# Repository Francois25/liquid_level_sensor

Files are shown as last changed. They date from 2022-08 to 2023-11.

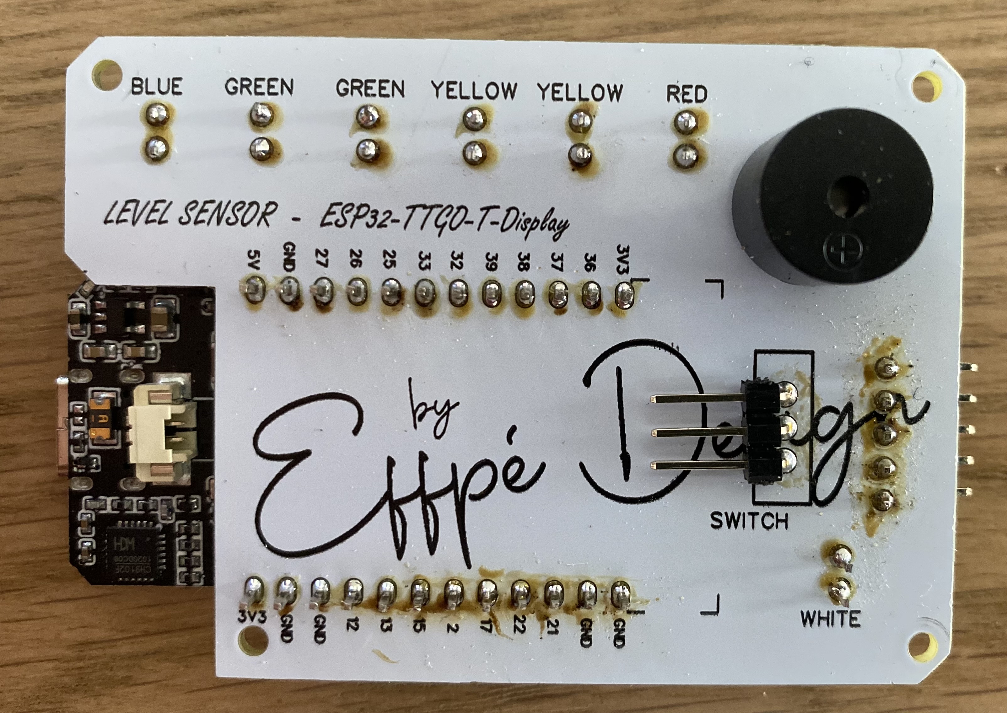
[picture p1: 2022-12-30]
Docs/pictures/IMG_4034.jpg

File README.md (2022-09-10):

# Liquid level sensor for tank presentation :

The tank liquid level sensor is an ultrasonic sensor housing. One housing is used to measure the height of a liquid in a rectangular tank and the other contains an analogue display of the data by means of coloured LEDs. The digital display is shown on the screen of an ESP32-TTGO-T-Display and on a web page.

# Micropython firmware :
The firmware used is Micropython, downloadable here: [MicroPython firmware for ESP32](https://micropython.org/download/esp32spiram/)  
The use of Picoweb allows to transmit the information on the web page using the address corresponding to the IP of the ESP card

# How it works : 
The ultrasonic sensor used here is the HCSR04. Coupled to this sensor is another temperature and humidity sensor, the DHT22 in order to calibrate the speed of sound in relation to temperature and humidity. In my case, the humidity had very little influence on the value of the ultrasonic measurement, so I didn't pay attention to it.
In the main.py file it is necessary to enter your own SSId and password on lines 15 and 16.

If there is a problem with the ultrasonic sensor, the screen will display an error message in red on a black background, so check the status of the sensor in the tank.
If there is a problem with the temperature sensor, the screen displays in red on a yellow background the temperature at 15° and the humidity at 0%.

All the libraries for the project to be functional can be found in the folder [/lib](https://github.com/Francois25/liquid_level_sensor/tree/master/lib)
All the fonts for the project to be functional are in the folder [/font](https://github.com/Francois25/liquid_level_sensor/tree/master/font)

# Addon :
The files needed to make the project work are in the folder [/Docs](https://github.com/Francois25/liquid_level_sensor/tree/master/Docs), you have BOM for buy all the parts you need, and a wiring diagram and Gerber ZIP.
You can find all 3D files for print different parts on folder [/STL](https://github.com/Francois25/liquid_level_sensor/tree/master/STL)

# Acknowledgements:
A big thank you to my friend Roel Jaspers who is always there when I get stuck on the code... Big Up Cyberjunkie.

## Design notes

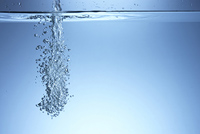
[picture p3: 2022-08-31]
web/goutte_eau.jpg

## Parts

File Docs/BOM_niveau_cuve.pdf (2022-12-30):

ID | Name | Designator | Footprint | Quantity
1 | HCSR04 | H1 | 20201128 SMA HCSR04 | 1
2 | LED-TH-5mm_Green | LED1,LED6 | LED-TH_BD5.0_GREEN | 2
3 | LED-TH-5mm_Red | LED2 | LED-TH_BD5.0_RED | 1
4 | LED-TH-5mm_White | LED3 | LED-TH_BD5.0_GREEN | 1
5 | LED-TH-5mm_Yellow | LED4,LED5 | LED-TH_BD5.0_RED | 2
6 | LED-TH-5mm_Blue | LED7 | LED-TH_BD5.0_BLUE | 1
7 | ESP32-TTGO-T-Display-V1.0 | P1 | ESP32-2X12-TTGO-TDISPLAY | 1
8 | 10k | R1,R2,R3,R4,R5,R6,R8 | R0805 | 7
9 | 390 | R7 | R0805 | 1
10 | SWITCH 2 positions | S2 | SWITCH-SPDT | 1
11 | Buzzer | U2 | BUZZER | 1
12 | DHT22 | U3 | SENSOR-TH_DHT11 | 1

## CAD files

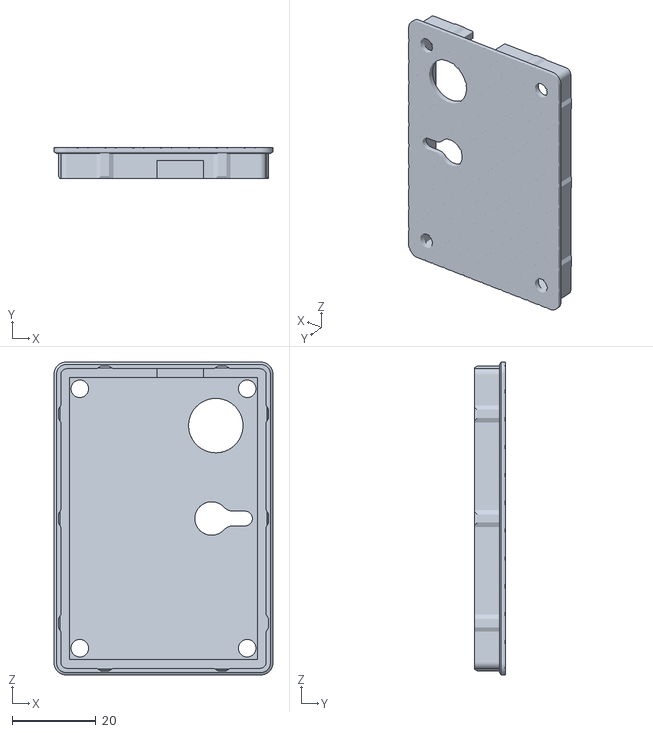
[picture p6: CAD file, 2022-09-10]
Docs/3D_print_STL/box_esp_rear.stl
52.3 x 7.50 x 74.8

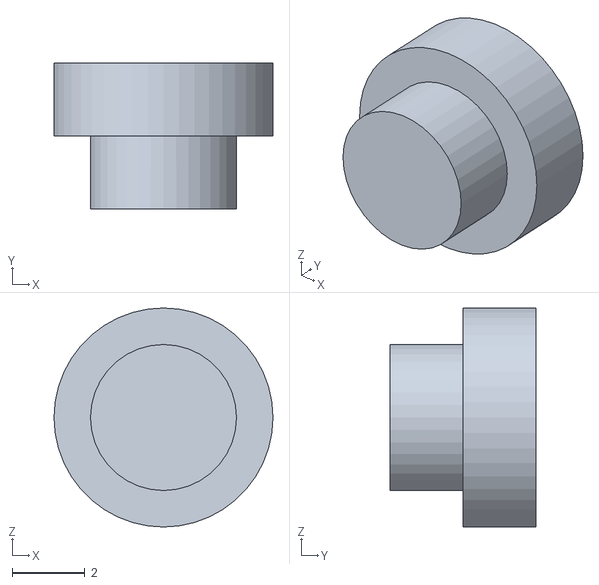
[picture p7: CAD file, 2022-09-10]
Docs/3D_print_STL/box_foot_rear.stl
6.00 x 4.00 x 6.00

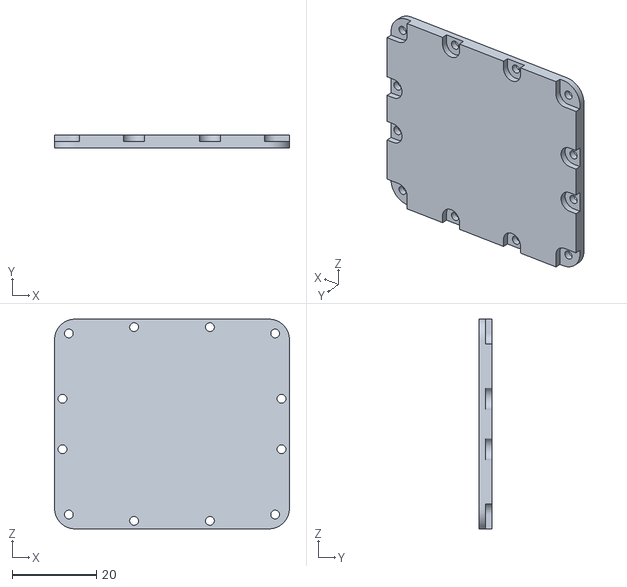
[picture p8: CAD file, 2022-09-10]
Docs/3D_print_STL/fond_boitier_hcsr04.stl
55.8 x 3.00 x 49.8

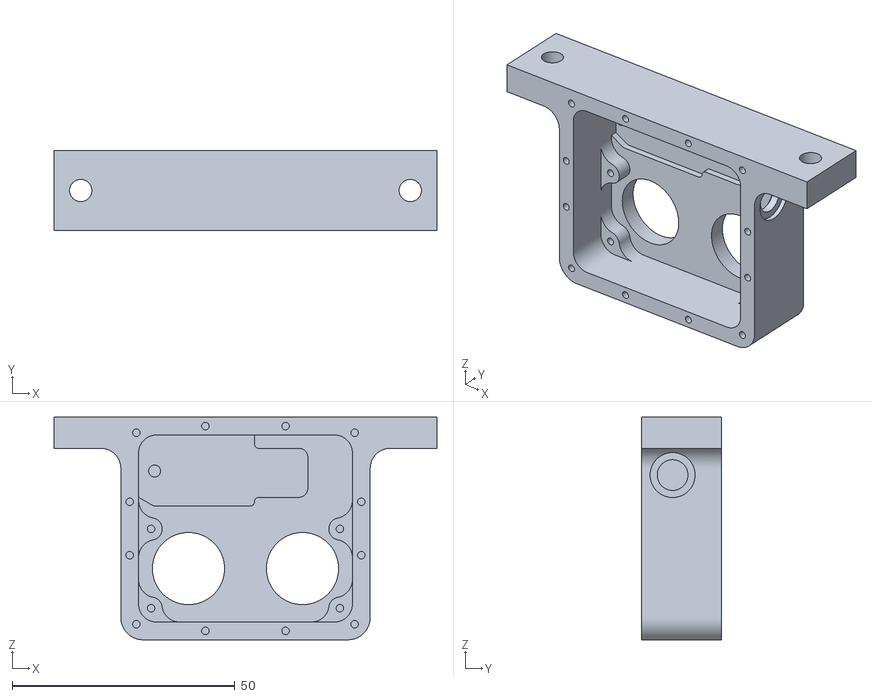
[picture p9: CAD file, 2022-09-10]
Docs/3D_print_STL/boitier_hcsr04.stl
86.0 x 18.0 x 50.0

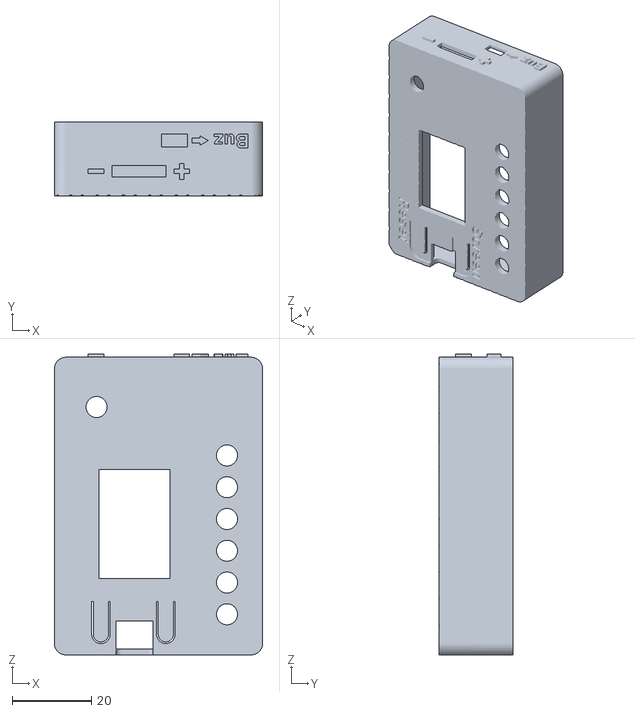
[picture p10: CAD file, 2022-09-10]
Docs/3D_print_STL/box_esp_sup.stl
52.5 x 18.6 x 75.8

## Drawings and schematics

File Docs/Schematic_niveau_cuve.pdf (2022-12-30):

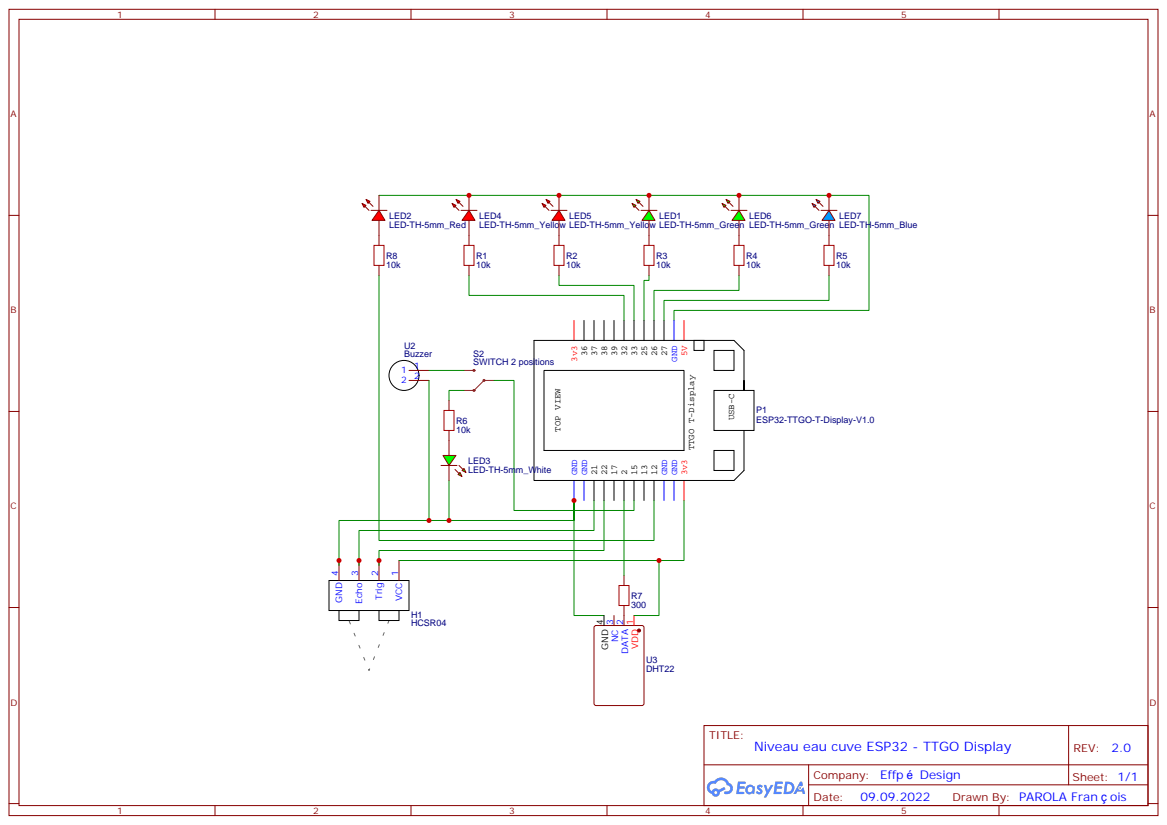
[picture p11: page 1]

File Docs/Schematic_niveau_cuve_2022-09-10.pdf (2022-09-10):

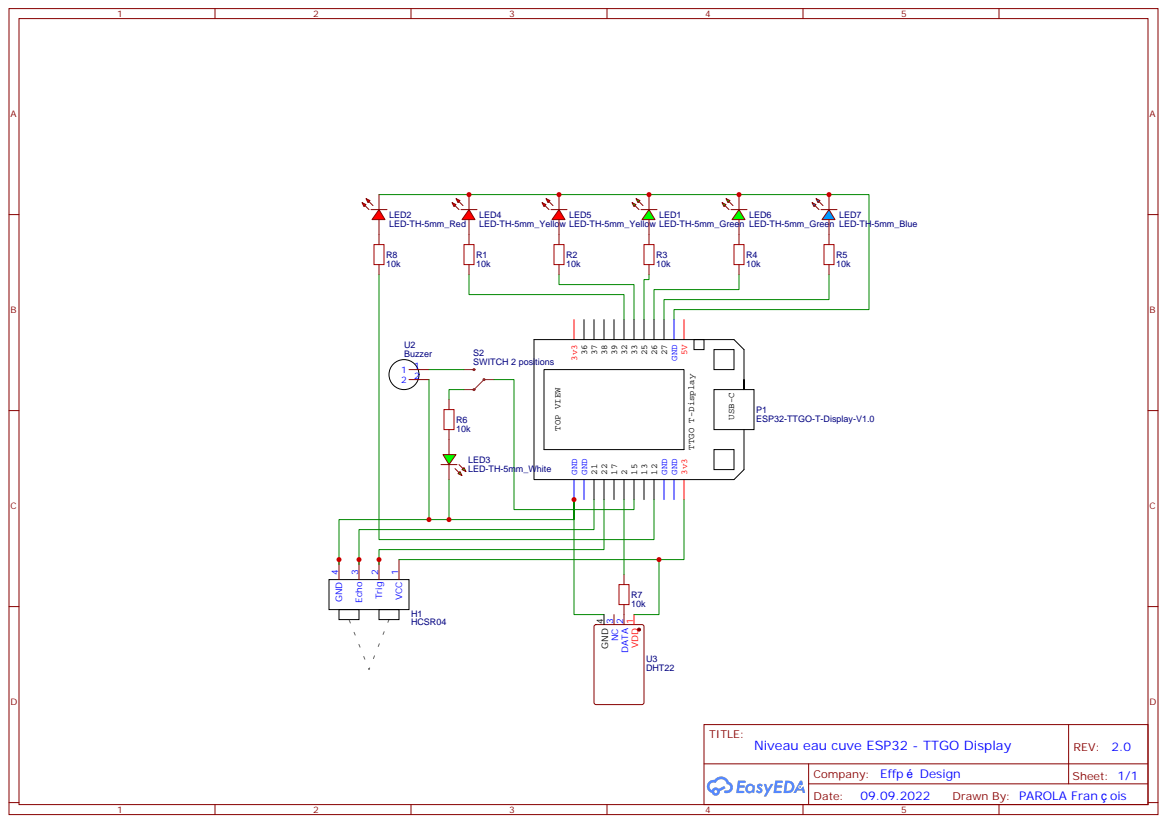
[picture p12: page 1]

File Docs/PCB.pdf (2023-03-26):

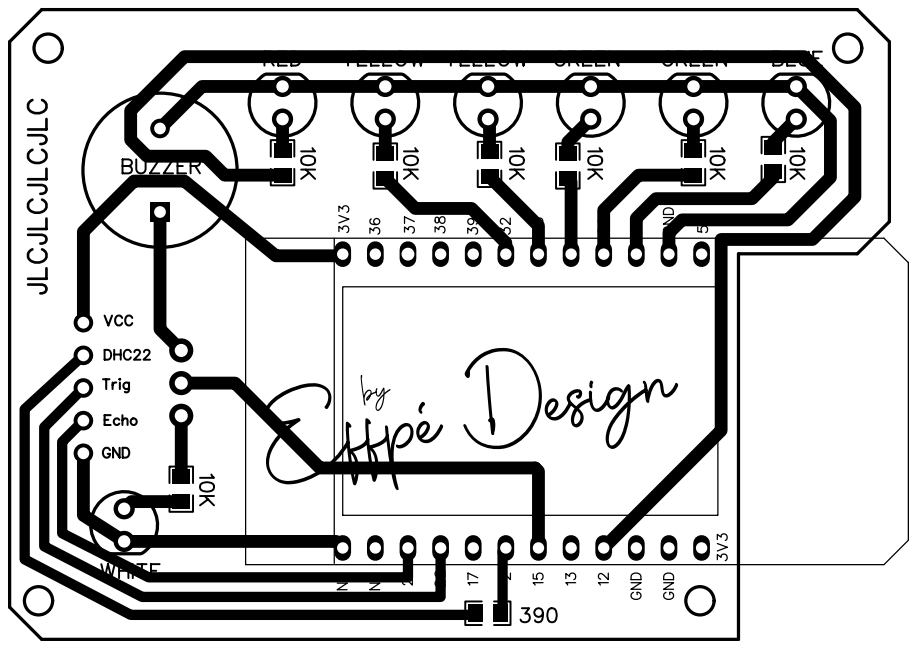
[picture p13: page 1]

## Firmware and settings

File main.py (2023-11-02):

import st7789py as st7789
from hcsr04 import HCSR04  # lib capteur HCSR-04

import capteur_temp_humi
import machine
import picoweb  # affichage de la page web, ajouter utemplate, pgk_ressources et ulogging aux lib
import utime
from machine import Pin, PWM, Timer  # lib utilisation module ESP32

import data_analyse
import tft_config  # lib tft pour affichage sur ttgo t-display
import wificonfig
import wificonnect
from romfonts import vga1_16x16 as font3
from romfonts import vga1_8x8 as font1
from romfonts import vga1_bold_16x32 as font4

# --------------------- WIFI ------------------------
#
# enter your wifi ssid and your password in wificonfig file

ipaddress = wificonnect.connectSTA(ssid=wificonfig.ssid, password=wificonfig.password)

# ------------------ SET UP --------------------------
# Taille de la cuve
MAXIMUM_WATER_LEVEL = 1.60  # hauteur d'eau maxi dans la cuve en m
SENSOR_POSITION = 0.22  # distance entre le capteur et le niveau maxi de la cuve en m
CUVE_X = 1.10  # taille de la cuve en X en m
CUVE_Y = 5.68  # taille de la cuve en Y en m
CAPACITE_CUVE = int(round(MAXIMUM_WATER_LEVEL * CUVE_X * CUVE_Y))

# definition des PIN du module ESP32 
frequence_led = 500
led_bleu = PWM(Pin(27, Pin.OUT, 0), frequence_led)
led_verte1 = PWM(Pin(26, Pin.OUT, 0), frequence_led)
led_verte2 = PWM(Pin(25, Pin.OUT, 0), frequence_led)
led_jaune1 = PWM(Pin(33, Pin.OUT, 0), frequence_led)
led_jaune2 = PWM(Pin(32, Pin.OUT, 0), frequence_led)
led_rouge = PWM(Pin(12, Pin.OUT, 0), frequence_led)
buzzer = PWM(Pin(15, Pin.OUT, 0))
button = Pin(35, Pin.IN, Pin.PULL_UP)
button_reset = Pin(0, Pin.IN, Pin.PULL_UP)

# Initialisation de l'écran tft
tfton = not button
tft = tft_config.config()
buzzer.duty(1)

# Définition des variables
SURFACE_CUVE = CUVE_X * CUVE_Y
VOLUME_MAX_CUVE = round(SURFACE_CUVE * MAXIMUM_WATER_LEVEL, 2)
timer = Timer(0)
previous_volume = 0


# Mesure de la température et de l'humidité avec le capteur DHT22
def temperature_humidity_measurement():
    temperature_humidity = capteur_temp_humi.sensor()  # temp, hum
    if temperature_humidity is not None:
        temp = round(temperature_humidity[0], 2)
        print("")
        print("temperature = ", temp)
        hum = round(temperature_humidity[1], 2)
        print("Humidity = ", hum)
        sound_speed = 331.3 + 0.606 * temp
        print(f"Sound speed : {sound_speed}")
        print('')
    else:
        temp = 15
        hum = 0
        sound_speed = 331.3 + 0.606 * temp
        screen_error_temp(temp, hum)

    return sound_speed, temp, hum


# Initialization des LED
def leds_init():
    led_bleu.duty(0)
    led_verte1.duty(0)
    led_verte2.duty(0)
    led_jaune1.duty(0)
    led_jaune2.duty(0)
    led_rouge.duty(0)


# Affichage erreur sur écran tft
def screen_error():
    tft.fill(st7789.BLACK)
    tft.text(font4, "MESURE FAILED", 15, tft.height // 3 - font4.HEIGHT // 2, st7789.RED, st7789.BLACK)
    text = "PUSH RESET"
    length_text = len(text)
    tft.text(font4, text, tft.width // 2 - length_text // 2 * font4.WIDTH, 2 * tft.height // 3 - font4.HEIGHT // 2,
             st7789.RED, st7789.BLACK)


# Affichage d'erreur de mesure température et/ou humidité sur l'écran tft
def screen_error_temp(temp, hum):
    text = f"T: {str(temp)} deg    -    H: {str(hum)} %"
    length_text = len(text)
    tft.text(font1, text, tft.width // 2 - length_text // 2 * font1.WIDTH, 120, st7789.RED, st7789.YELLOW)


# Allumage des LED selon le niveau d'eau mesuré
def analogue_display(volume):
    leds_init()
    buzzer.duty(1)
    if VOLUME_MAX_CUVE > volume >= 0.1 * VOLUME_MAX_CUVE:
        if volume >= 0.9 * VOLUME_MAX_CUVE:
            led_bleu.duty(50)
        elif 0.8 * VOLUME_MAX_CUVE <= volume < 0.9 * VOLUME_MAX_CUVE:
            led_verte1.duty(30)
        elif 0.6 * VOLUME_MAX_CUVE <= volume < 0.8 * VOLUME_MAX_CUVE:
            led_verte2.duty(30)
        elif 0.4 * VOLUME_MAX_CUVE <= volume < 0.6 * VOLUME_MAX_CUVE:
            led_jaune1.duty(30)
        elif 0.2 * VOLUME_MAX_CUVE <= volume < 0.4 * VOLUME_MAX_CUVE:
            led_jaune2.duty(30)
        elif 0.1 * VOLUME_MAX_CUVE <= volume < 0.2 * VOLUME_MAX_CUVE:
            led_rouge.duty(10)
    elif 0 <= volume < 0.1 * VOLUME_MAX_CUVE:
        buzzer.duty(250)
        led_rouge.duty(30)
    elif volume < 0:     
        buzzer.duty(250)
        led_rouge.duty(30)
        led_jaune2.duty(30)
        led_verte2.duty(30)
        led_bleu.duty(30)
    elif volume >= VOLUME_MAX_CUVE:
        led_bleu.duty(100)


# Calcul du volume d'eau dans la cuve
def calculation_volume(sound_speed, temp):
    data = []
    try:
        for i in range(10):
            mesure = HCSR04(trigger_pin=22, echo_pin=21)
            distance_mesuree = mesure.distance_cm() / (1000000 / sound_speed)
            data.append(distance_mesuree)
            print("mesurement ", i, ": ", distance_mesuree)
            utime.sleep(0.5)
        maxi = max(data)
        mini = min(data)
        data.remove(maxi)
        data.remove(mini)
        distance_moyenne = sum(data) / len(data)
        print(f'Valeurs exclues => mini: {round(mini, 4)} et maxi: {round(maxi), 4}')
        if distance_moyenne > 0:
            print(f"Average distance: {round(distance_moyenne, 4)}m")
            volume_available = round(((MAXIMUM_WATER_LEVEL + SENSOR_POSITION) * SURFACE_CUVE) - (distance_moyenne * SURFACE_CUVE), 2)
            print(f"Available volume used: {volume_available}m3")
            return volume_available
        else:
            print("Mesurement <= 0, no sensor response")
            screen_error()
    except Exception:
        print('EXPECT : MEASUREMENT FAILED - SENSOR HCSR KO')
        screen_error()


# Affichage du la hauteur d'eau sur l'écran tft
def digital_display(volume, hum, temp):
    if volume >= (0.95 * VOLUME_MAX_CUVE):
        tft.fill(st7789.CYAN)
        tft.text(font4, "FULL TANK ", 40, tft.height // 2 - font4.HEIGHT // 2, st7789.BLUE, st7789.CYAN)
    elif VOLUME_MAX_CUVE > volume >= 0.1 * VOLUME_MAX_CUVE:
        tft.fill(st7789.BLACK)
        tft.text(font4, "TANK LEVEL", 35, 10, st7789.CYAN)
        tft.text(font3, f"Capacity: {str(CAPACITE_CUVE)}m3", 6, 55, st7789.YELLOW)
        text = f"Remainder:{str(volume)}"
        length_text = len(text)
        tft.text(font3, text, tft.width // 2 - length_text // 2 * font3.WIDTH, 80, st7789.GREEN)
    elif 0 <= volume < 0.1 * VOLUME_MAX_CUVE:
        tft.fill(st7789.YELLOW)
        tft.text(font4, "EMPTY TANK", 45, tft.height // 3 - font4.HEIGHT // 2, st7789.RED, st7789.YELLOW)
        tft.text(font4, "LEVEL < 1 m3", 15, (tft.height // 3) * 2 - font4.HEIGHT // 2, st7789.RED, st7789.YELLOW)
    else:
        screen_error()
    if temp == 15 and hum == 0:
        screen_error_temp(temp, hum)
    else:
        text = f"T: {str(temp)} deg  -  H: {str(hum)} %"
        length_text = len(text)
        tft.text(font1, text, tft.width // 2 - length_text // 2 * font1.WIDTH, 120, st7789.CYAN)


# Allumage de l'écran par appui sur le bouton
def button_push(p):
    tft.sleep_mode(False)
    utime.sleep(5)
    tft.sleep_mode(True)


def button_push_reset(p):
    machine.reset()


# Gestion du système
def handleInterrupt(timer, tfton, previous_volume):
    mesure = temperature_humidity_measurement()  # return sound_speed, temp, hum
    sound_speed = mesure[0]
    temp = mesure[1]
    hum = mesure[2]
    volume_available = calculation_volume(sound_speed, temp)  # round(uniform(9, 10.0), 2)       # return volume_available
    if volume_available:
        digital_display(volume_available, hum, temp)
        if tfton:
            return not tfton
        else:
            tft.sleep_mode(True)
        analogue_display(volume_available)
    if volume_available != previous_volume:
        previous_volume = volume_available
        data_analyse.send_data(volume_available, temp)    
    else:
        print("ERROR : Impossible mesurement")
    timer.init(period=300000, mode=Timer.PERIODIC, callback=handleInterrupt(timer, tfton, previous_volume))  # refresh toutes les minutes


# ---------------------------------------------------------
# --------------------- START PROGRAMME -------------------
# Allumage de l'écran à la mise sous tension
tft.fill(st7789.GREEN)
text = "POWER ON"
length_text = len(text)
tft.text(font4, text, tft.width // 2 - length_text // 2 * font4.WIDTH, 30, st7789.RED, st7789.GREEN)
text = "WAIT...."
length_text = len(text)
tft.text(font4, text, tft.width // 2 - length_text // 2 * font4.WIDTH, 75, st7789.RED, st7789.GREEN)
utime.sleep(3)

# Utilisation du bouton de facade pour allumer l'écran
button.irq(trigger=Pin.IRQ_FALLING, handler=button_push)
button_reset.irq(trigger=Pin.IRQ_FALLING, handler=button_push_reset)
handleInterrupt(timer, tfton, previous_volume)

# ---- Routing Picoweb ------------------------------------
app = picoweb.WebApp(__name__)


@app.route("/")
def index(req, resp):
    yield from picoweb.start_response(resp)
    yield from app.sendfile(resp, '/web/index.html')


@app.route("/get_data")
def get_volume(req, resp):
    yield from picoweb.jsonify(resp, {'volume': volume_available, 'temperature': temp, 'humidite': hum})


@app.route("/style.css")
def css(req, resp):
    print("Send style.css")
    yield from picoweb.start_response(resp)
    yield from app.sendfile(resp, '/web/style.css')


@app.route("/goutte_eau.jpg")
def index(req, resp):
    yield from picoweb.start_response(resp)
    try:
        with open("web/goutte_eau.jpg", 'rb') as img_binary:
            img = img_binary.read()
        yield from resp.awrite(img)
        print("Send JPG")
    except Exception:
        print("Image file not found.")


app.run(debug=True, host=ipaddress, port=80)

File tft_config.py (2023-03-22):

""" LilyGo T-DISPLAY 135x240 ST7789 display """

from machine import Pin, SPI, SoftSPI
import st7789py as st7789

TFA = 40
BFA = 40

def config(rotation=1):
    spi = SoftSPI(
    baudrate=20000000,
    polarity=1,
    phase=0,
    sck=Pin(18),
    mosi=Pin(19),
    miso=Pin(13))

    
    return st7789.ST7789(
        spi,
        135,
        240,
        reset=Pin(23, Pin.OUT),
        cs=Pin(5, Pin.OUT),
        dc=Pin(16, Pin.OUT),
        backlight=Pin(4, Pin.OUT),
        rotation=rotation
        #options=options,
        #buffer_size= buffer_size
        )

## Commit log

2022-09-03 calibration du niveau selon la température
2022-09-10 ajout des documents, 3D, STL et schémas
    Ajout des fichiers 3D pour l'impression, des 3D de construction ainsi que des fichiers de câblage et nomenclature.
    [boitier_hcsr04.stl, box_esp_rear.stl, box_esp_sup.stl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]
2022-12-30 main : wifi config add file, buzzer fixed
    [main.py]
2022-12-30 resistor change, pics new version, new gerber
2023-03-22 Squashed commit of the following:
    commit f083ef0e79cbaa2deaba351c2c53c60214f27ffa
    Author: FoxtrotPapa_25 <Francois25@users.noreply.github.com>
    Date: Sun Mar 19 14:23:14 2023 +0100
    nouvelles font
    commit 6e5ca743cbd81387a2b0b8c69f9cd2f0ed42ee9a
    Author: FoxtrotPapa_25 <Francois25@users.noreply.github.com>
    Date: Sun Mar 19 14:21:30 2023 +0100
    retrait des font modifiées
    commit 463bf0e6f503b48f3f10017f2e25078867290647
    Author: FoxtrotPapa_25 <Francois25@users.noreply.github.com>
    Date: Sun Mar 19 14:20:57 2023 +0100
    gestion bug de distance
    commit 16814dccde99c275f8005963857c8c8f92448c1d
    Author: FoxtrotPapa_25 <Francois25@users.noreply.github.com>
    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
    [data_analyse.py, main.py, tft_config.py]
2023-03-26 ajout plan pcb et plan DHT22
    ajout des plans pour branchement
2023-11-02 nouvelle image de fond et icone
